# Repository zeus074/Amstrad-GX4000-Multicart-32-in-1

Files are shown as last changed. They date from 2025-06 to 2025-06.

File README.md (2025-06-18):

# AMSTRAD GX4000 / CPC464+ MULTICART
32 IN 1 SMD

This cartridge allows programs to run on the Amstrad GX4000 or CPC464+ computer

It uses two MX29F1610 ROMs to store up to 16 programs of 128kb each.

With the switch on top of the cartridge it is possible to select which rom to use, while with the dipswitch the bank is selected from 0 to 15, for a total of 32 games.

Amstrad uses a protection system for these cartridges, you can use the original chip **acid** (taken from another cartridge) or a 74HC112N flip-flop.

PCB:

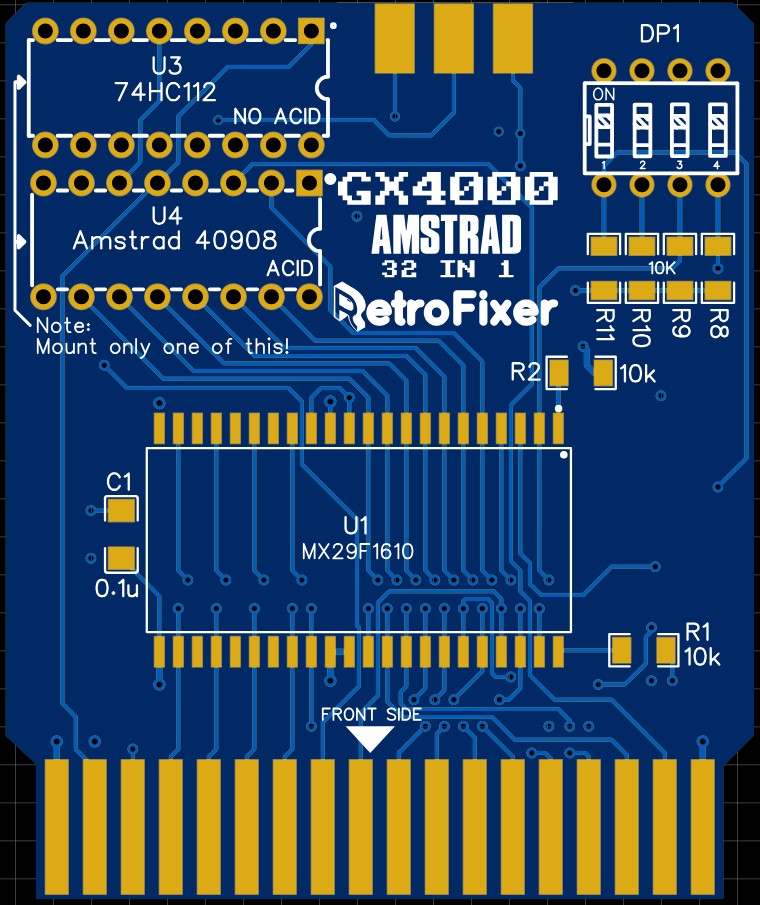
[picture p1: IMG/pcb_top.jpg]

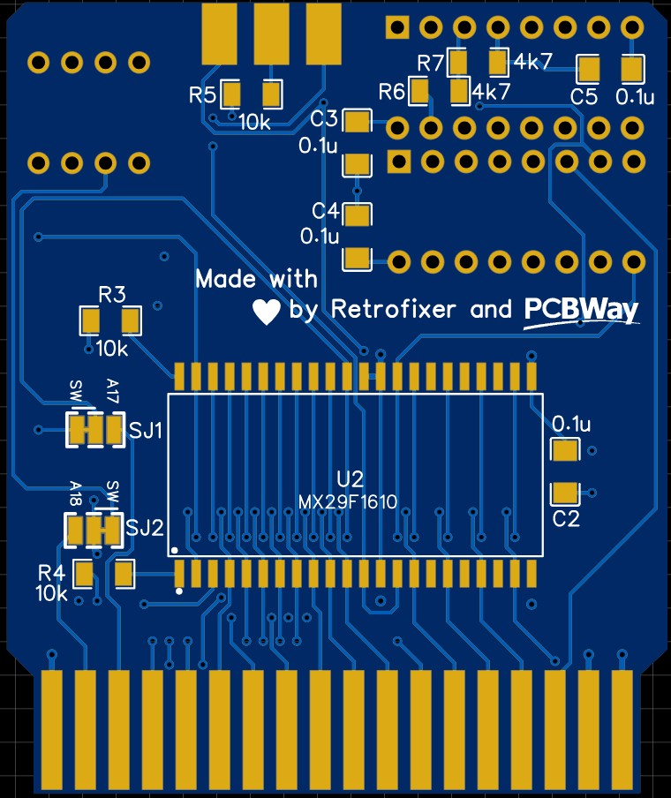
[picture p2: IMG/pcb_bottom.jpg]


:coffee: if you want the PCB, please support me and follow this link : <a href="https://www.pcbway.com/project/shareproject/Amstrad_GX4000_multicart_or_CPC464_32in_1_SMD_3feb920f.html" target="_NEW">PCBWAY!</a>

You can find the video of this project on the Retrofixer channel: link

Please consider subscribing to the channel, it's free and helps us to improve and always offer you new videos and more!

**Components:**

R3,R4,R1,R2,R8,R9,R10,R11,R5: 10K (1206)

R6,R7: 4K7 (1206)

C5,C3,C4,C2,C1: .1uF (1206)

C1,C2,C3,C4: 100nF ceramic

U1,U2: MX29F1610MC-10 (SOP44)

Mount Amstrad 40908 (U4) or the 74HC112N (U3) "Do not use them together!"

DP1: Dip-switch (4pin)

SW1: Slide switch 2 position (DPDT)

*Resistors r10 or r11 can not be mounted if the respective inputs A17 or A18 are used by the console and not managed by the dipswitch

**Realization:**

the gx4000 has a system to prevent the insertion of the cartridge with the console on and removal, it is necessary that the flaps of the slot are all open otherwise the switch remains blocked. 

To overcome this you can enlarge them by hand or make a case for the cartridge, if you make the case, the chips must be soldered on the pcb without a socket, otherwise the card will be too thick.

Behind the card there are 2 jumpers JP17 and JP18 which can be closed in position SW or A17,A18.

If they are to be used for 128k games, they must be set to SW, so 16 games can be managed in the dipswitch.

If you use larger roms these can be managed by the console by making the jumper between the central pin and the relative input.

This change (JP17,JP18) affects both roms.

You can find schemnatic and BOM in the relative folders.

**Final cartridge:**

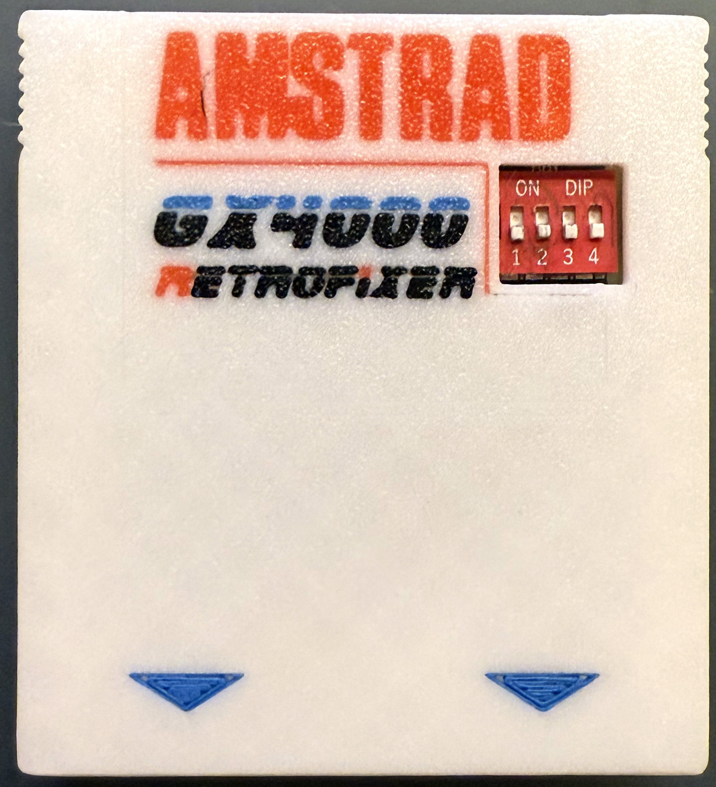
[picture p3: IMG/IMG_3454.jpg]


Ofcourse! This case is in the 3D_Print folder.

Subscribe to my channel Retrofixer https://www.youtube.com/@retrofixer to keep us going in this work.

You can print ready-made pcb on PCBWAY! https://www.pcbway.com/project/shareproject/Amstrad_GX4000_multicart_or_CPC464_32in_1_SMD_3feb920f.html

Enjoy!

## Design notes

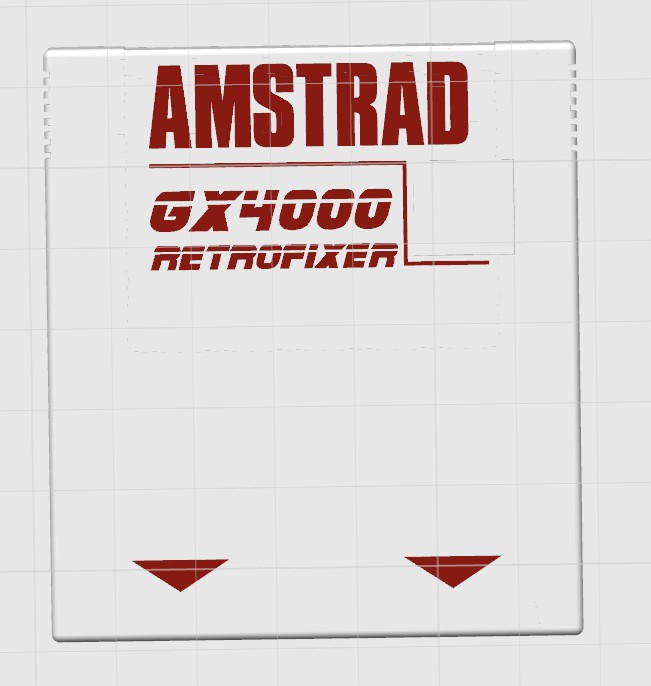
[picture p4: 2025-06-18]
IMG/3d_cart.jpg

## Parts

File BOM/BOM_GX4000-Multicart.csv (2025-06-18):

ID | Name | Designator | Footprint | Quantity | Manufacturer Part | Manufacturer | Supplier | Supplier Part | Price
1 | DipSwitch4 | DP1 | SW-TH_DIPSWITCHEI-04 | 1
2 | 10k | R3,R4,R1,R2,R8,R9,R10,R11,R5 | R1206 | 9
3 | 0.1u | C5,C3,C4,C2,C1 | C1206 | 5
4 | 4k7 | R6,R7 | R1206 | 2
6 | MX29F1610MC-10 on SOP-44 | U2,U1 | SOP-44_L28.2-W13.3-P1.27-LS16.0-BL | 2
8 | Slide_Switch_DPDT_horizontal | SW1 | SLIDE_SWITCH_DPDT_HORIZONTAL | 1 | Multicomp | Multicomp
9 | MC74HC112N | U3 | PDIP-16_L19.7-W6.6-P2.54-LS7.6-BL | 1 | MC74HC112N
10 | Socket for Amstrad 40908 ACID | U4 | PDIP-16_L19.3-W6.6-P2.54-LS7.6-BL | 1

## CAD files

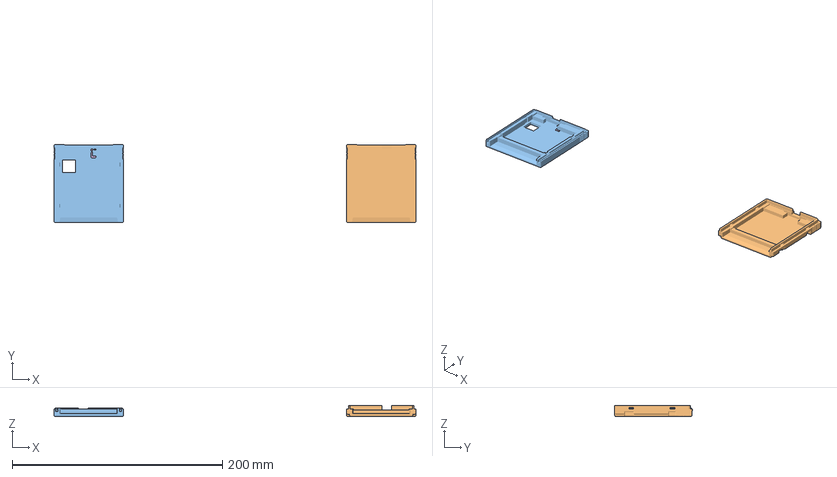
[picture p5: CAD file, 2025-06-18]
3D_Print/GX4000_multicart_MINI.3mf
344.2 x 73.8 x 10.2 mm
Corpo10
Corpo11
Corpo12
Corpo13
Corpo14
Corpo15
Corpo16
Corpo17
Corpo18
Corpo19
Corpo20
Corpo21
Corpo22
Corpo23
Corpo24
Corpo25
Corpo26
Corpo27
Corpo28
Corpo29
Corpo30
Corpo31
Corpo32
Corpo33
Corpo34
Corpo35
Corpo36
Corpo37
Corpo38
Corpo39
Corpo40
Corpo41
Corpo42
Corpo43
Corpo44
Corpo45
Corpo46
Corpo47
Corpo48
Corpo49
Corpo50
Shell_v2-Bottom
Shell_v2-Top

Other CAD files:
3D_Print/GX4000_multicart_MINI_color.3mf
3D_Print/GX4000_multicart_MINI.stl

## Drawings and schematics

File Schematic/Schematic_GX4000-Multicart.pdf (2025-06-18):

## ROMS

## Decoupling

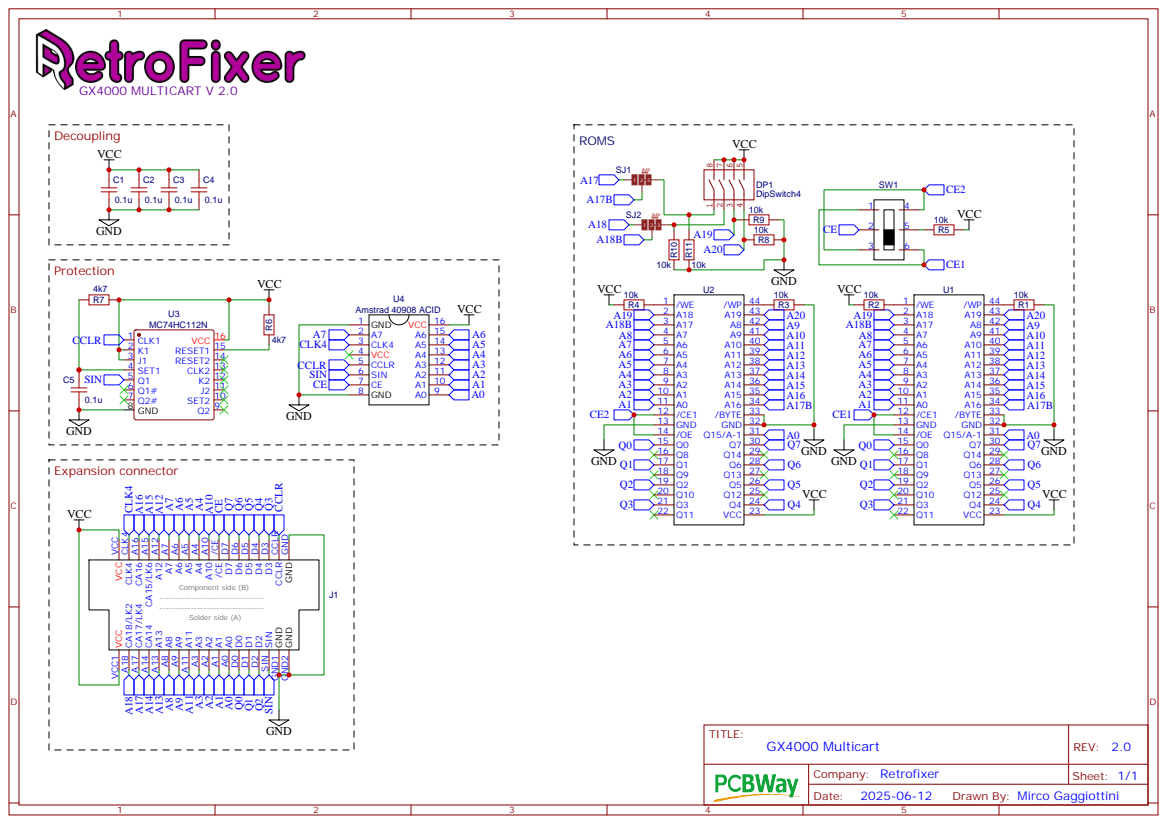
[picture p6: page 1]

Drawn By: Mirco Gaggiottini
